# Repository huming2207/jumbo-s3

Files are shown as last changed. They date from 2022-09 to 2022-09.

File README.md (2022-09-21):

# jumbo-s3

PoC hardware design of ESP32-S3FN8 + 16MB (APS12808L-3OBM-BA) PSRAM

## Intro

As of September 2022, Espressif doesn't provide an official solution for ESP32-S3 that comes with more than 8MB PSRAM. However someone mentioned that the APS12808L works with ESP32-S3 but no open source design.

Therefore here comes my solution. It has been proven working fine. No modification needed for ESP-IDF. As long as the PSRAM support is enabled and set to octal mode, 80MHz, it should just works.

## Log

Here's a simple boot log that runs the APS12808L in octal SPI mode at 80MHz, and logs the free heap size.

```
ESP-ROM:esp32s3-20210327
Build:Mar 27 2021
rst:0x1 (POWERON),boot:0x8 (SPI_FAST_FLASH_BOOT)
SPIWP:0xee
mode:DIO, clock div:1
load:0x3fce3810,len:0x1808
load:0x403c9700,len:0xd6c
load:0x403cc700,len:0x2ed4
entry 0x403c992c
I (24) boot: ESP-IDF v5.1-dev-862-g09f7589ef2 2nd stage bootloader
I (25) boot: compile time Sep 20 2022 23:02:14
I (25) boot: chip revision: V001
I (29) boot_comm: chip revision: 1, min. bootloader chip revision: 0
I (36) qio_mode: Enabling default flash chip QIO
I (42) boot.esp32s3: Boot SPI Speed : 80MHz
I (46) boot.esp32s3: SPI Mode       : QIO
I (51) boot.esp32s3: SPI Flash Size : 4MB
I (56) boot: Enabling RNG early entropy source...
I (61) boot: Partition Table:
I (65) boot: ## Label            Usage          Type ST Offset   Length
I (72) boot:  0 nvs              WiFi data        01 02 00009000 00006000
I (79) boot:  1 phy_init         RF data          01 01 0000f000 00001000
I (87) boot:  2 factory          factory app      00 00 00010000 00100000
I (94) boot: End of partition table
I (99) boot_comm: chip revision: 1, min. application chip revision: 0
I (106) esp_image: segment 0: paddr=00010020 vaddr=3c020020 size=08a5ch ( 35420) map
I (120) esp_image: segment 1: paddr=00018a84 vaddr=3fc92700 size=03268h ( 12904) load
I (125) esp_image: segment 2: paddr=0001bcf4 vaddr=40374000 size=04324h ( 17188) load
I (135) esp_image: segment 3: paddr=00020020 vaddr=42000020 size=196fch (104188) map
I (155) esp_image: segment 4: paddr=00039724 vaddr=40378324 size=0a30ch ( 41740) load
I (164) esp_image: segment 5: paddr=00043a38 vaddr=50000000 size=00010h (    16) load
I (170) boot: Loaded app from partition at offset 0x10000
I (170) boot: Disabling RNG early entropy source...
I (184) octal_psram: vendor id    : 0x0d (AP)
I (184) octal_psram: dev id       : 0x02 (generation 3)
I (184) octal_psram: density      : 0x05 (128 Mbit)
I (189) octal_psram: good-die     : 0x01 (Pass)
I (195) octal_psram: Latency      : 0x01 (Fixed)
I (200) octal_psram: VCC          : 0x01 (3V)
I (205) octal_psram: SRF          : 0x01 (Fast Refresh)
I (211) octal_psram: BurstType    : 0x01 (Hybrid Wrap)
I (217) octal_psram: BurstLen     : 0x01 (32 Byte)
I (222) octal_psram: Readlatency  : 0x02 (10 cycles@Fixed)
I (228) octal_psram: DriveStrength: 0x00 (1/1)
W (233) PSRAM: DO NOT USE FOR MASS PRODUCTION! Timing parameters will be updated in future IDF version.
I (244) esp_psram: Found 16MB PSRAM device
I (248) esp_psram: Speed: 80MHz
I (252) cpu_start: Pro cpu up.
I (256) cpu_start: Starting app cpu, entry point is 0x40375378
I (0) cpu_start: App cpu up.
I (1167) esp_psram: SPI SRAM memory test OK
I (1176) cpu_start: Pro cpu start user code
I (1176) cpu_start: cpu freq: 160000000 Hz
I (1176) cpu_start: Application information:
I (1179) cpu_start: Project name:     main
I (1184) cpu_start: App version:      1
I (1188) cpu_start: Compile time:     Sep 20 2022 23:02:12
I (1195) cpu_start: ELF file SHA256:  1f3449a15147ac7a...
Warning: checksum mismatch between flashed and built applications. Checksum of built application is e6bd8ac9c4e022dd86afd168d00707482f76b53ee256de9e101a4846cd271af5
I (1201) cpu_start: ESP-IDF:          v5.1-dev-862-g09f7589ef2
I (1207) heap_init: Initializing. RAM available for dynamic allocation:
I (1215) heap_init: At 3FC963E8 len 00053328 (332 KiB): D/IRAM
I (1221) heap_init: At 3FCE9710 len 00005724 (21 KiB): STACK/DRAM
I (1228) heap_init: At 3FCF0000 len 00008000 (32 KiB): DRAM
I (1234) heap_init: At 600FE010 len 00001FF0 (7 KiB): RTCRAM
I (1241) esp_psram: Adding pool of 16384K of PSRAM memory to heap allocator
I (1249) spi_flash: detected chip: gd
I (1253) spi_flash: flash io: qio
W (1257) spi_flash: Detected size(8192k) larger than the size in the binary image header(4096k). Using the size in the binary image header.
I (1270) cpu_start: Starting scheduler on PRO CPU.
I (0) cpu_start: Starting scheduler on APP CPU.
I (1290) esp_psram: Reserving pool of 32K of internal memory for DMA/internal allocations
I (1290) test: Lay hou
I (1300) test: Max heap: 17117304

```

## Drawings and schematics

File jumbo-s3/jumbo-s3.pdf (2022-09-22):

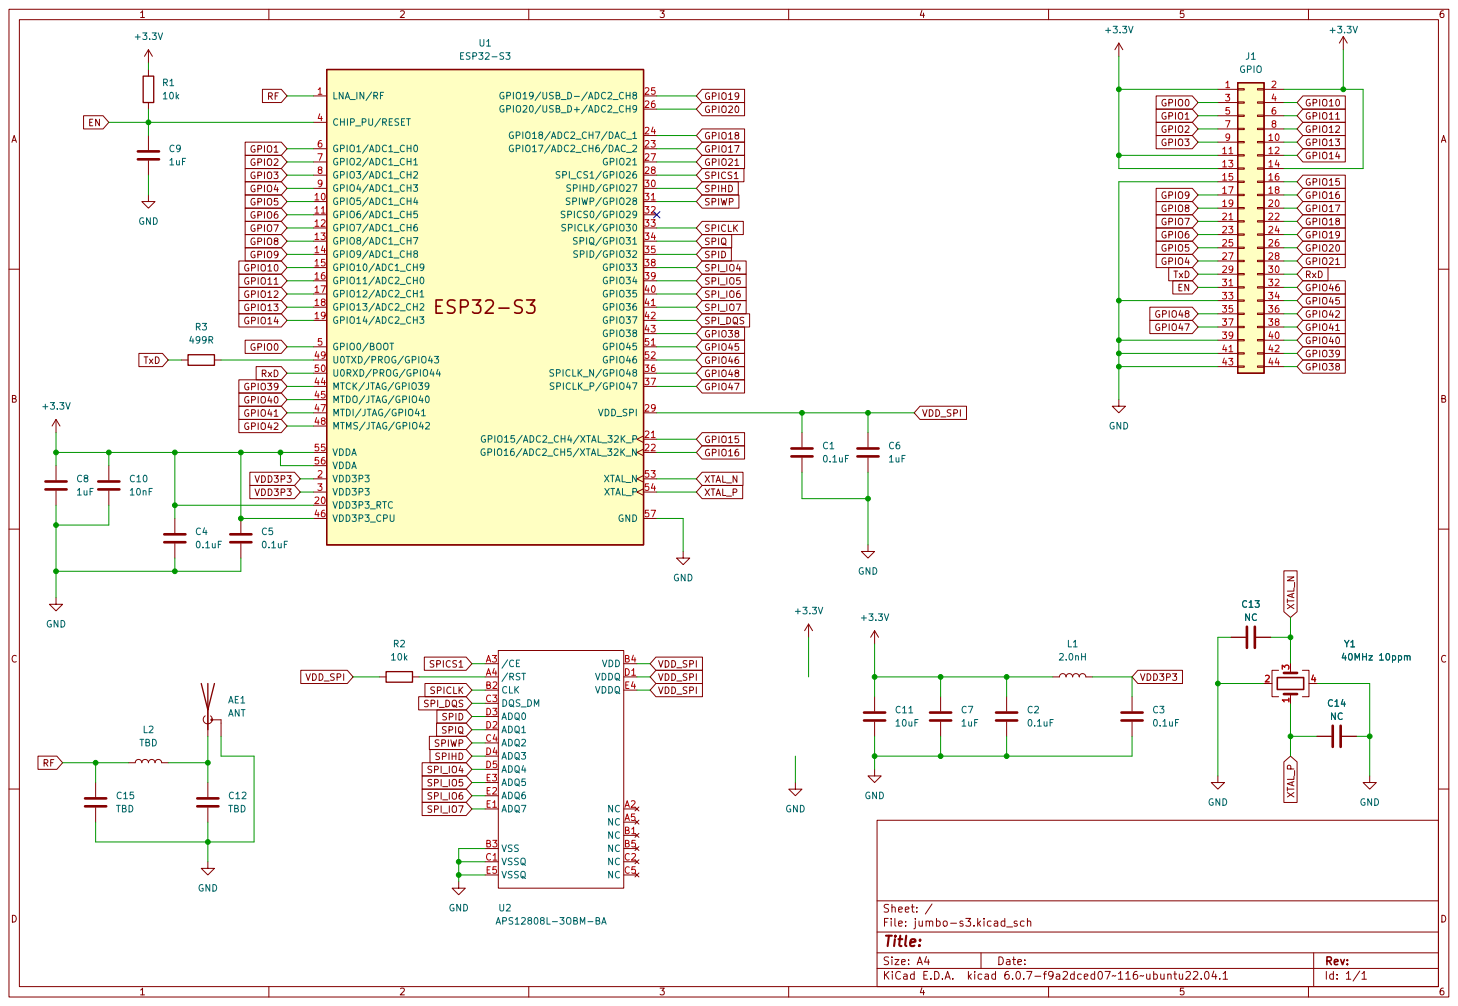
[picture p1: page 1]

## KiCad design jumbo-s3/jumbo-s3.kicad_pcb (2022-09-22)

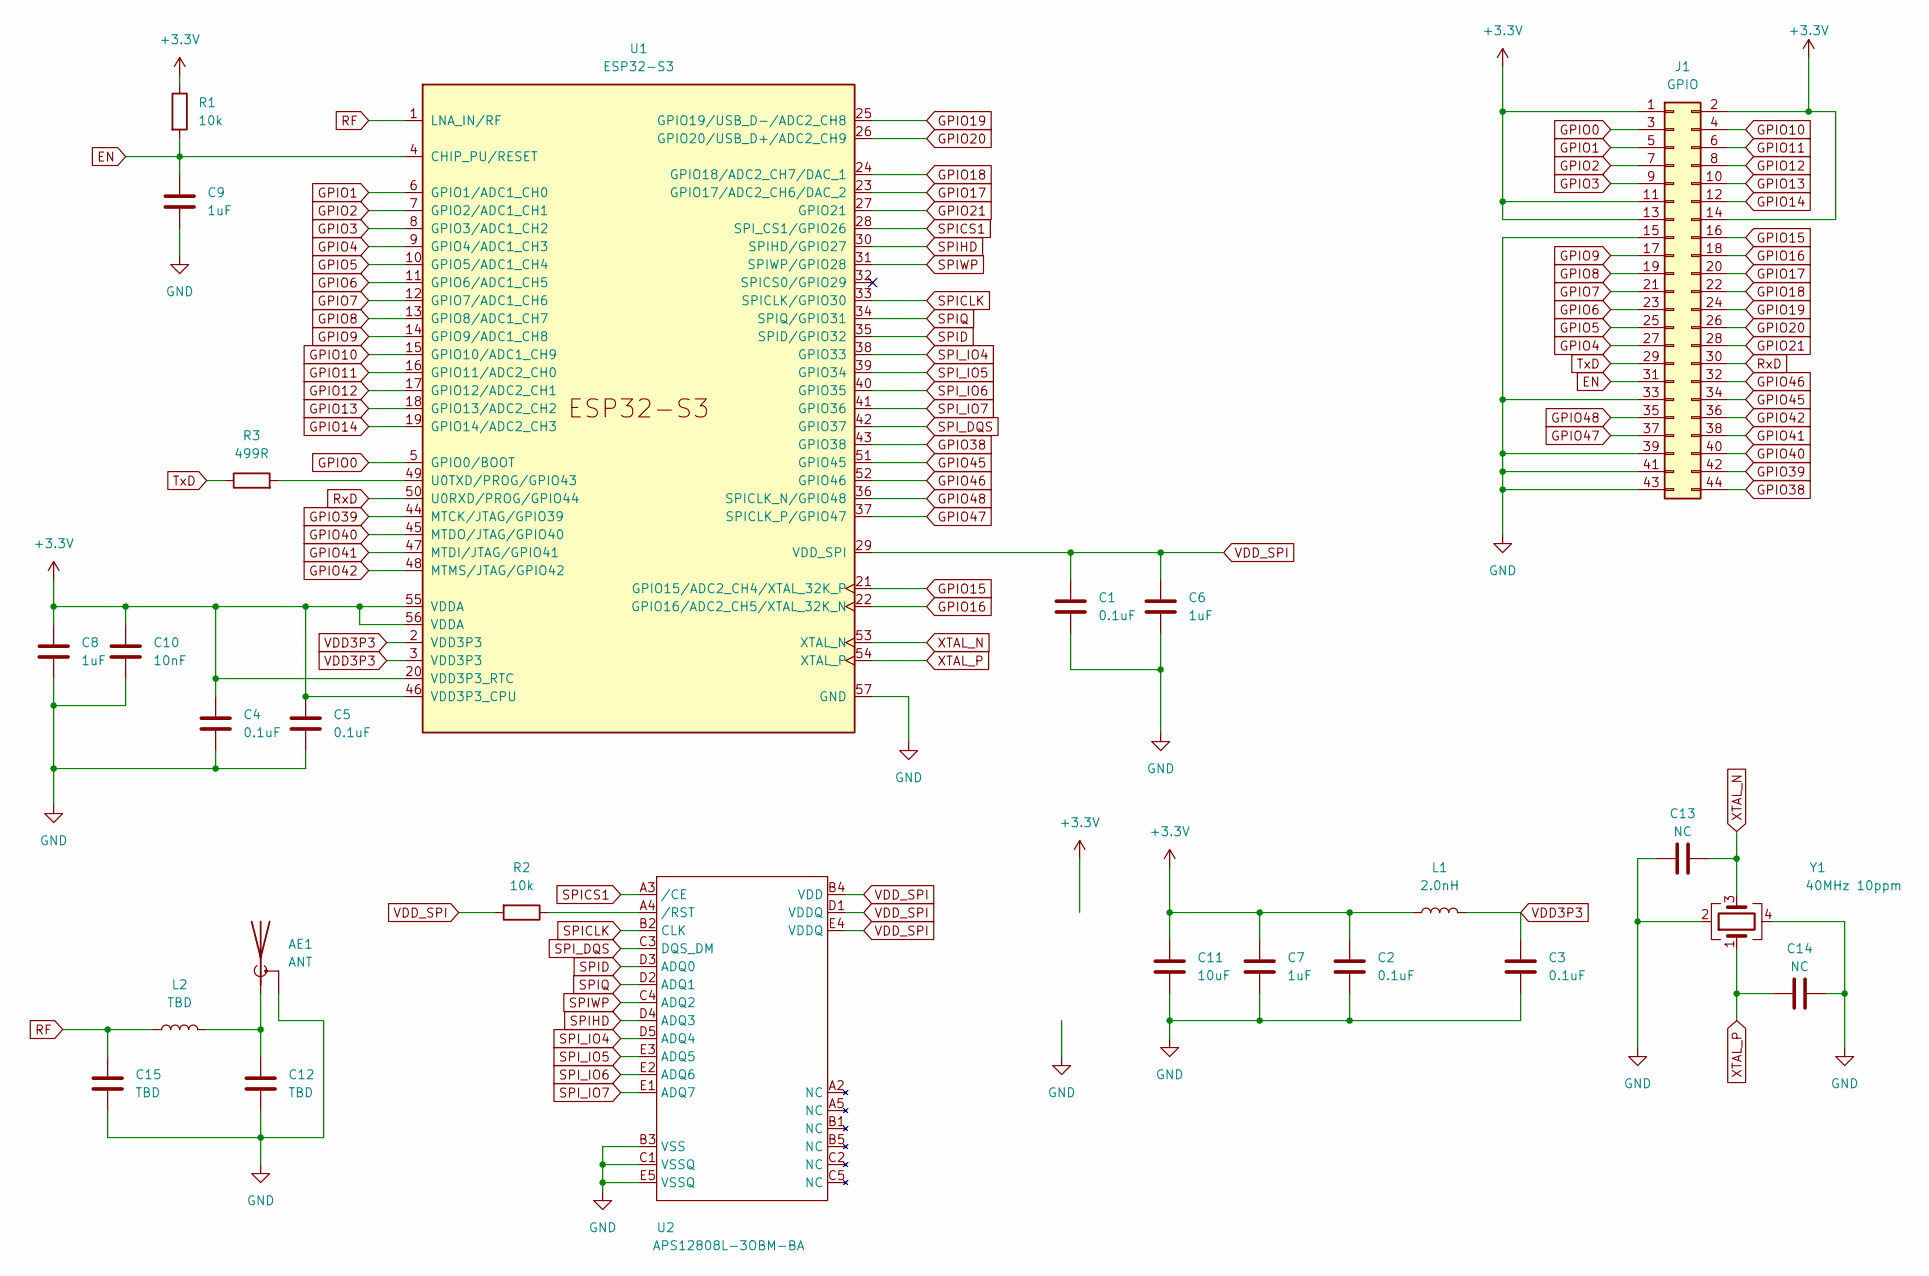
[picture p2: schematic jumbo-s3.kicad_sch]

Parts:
AE1: ANT; Texas_SWRA117D_2.4GHz_Left
C1, C2, C3, C4, C5: 0.1uF; C_0603_1608Metric_Pad1.08x0.95mm_HandSolder
C6, C7, C8, C9: 1uF; C_0603_1608Metric_Pad1.08x0.95mm_HandSolder
C10: 10nF; C_0603_1608Metric_Pad1.08x0.95mm_HandSolder
C11: 10uF; C_0603_1608Metric_Pad1.08x0.95mm_HandSolder
C12, C15: TBD; C_0603_1608Metric_Pad1.08x0.95mm_HandSolder
C13, C14: NC; C_0603_1608Metric_Pad1.08x0.95mm_HandSolder
J1: GPIO; PinHeader_2x22_P1.27mm_Vertical_SMD
L1: 2.0nH; L_0603_1608Metric_Pad1.05x0.95mm_HandSolder
L2: TBD; L_0603_1608Metric_Pad1.05x0.95mm_HandSolder
R1, R2: 10k; R_0603_1608Metric_Pad0.98x0.95mm_HandSolder
R3: 499R; R_0603_1608Metric_Pad0.98x0.95mm_HandSolder
U1: ESP32-S3; QFN-56-1EP_7x7mm_P0.4mm_EP5.6x5.6mm
U2: APS12808L-3OBM-BA; MINIBGA-24L
Y1: 40MHz 10ppm; Crystal_SMD_3225-4Pin_3.2x2.5mm_HandSoldering

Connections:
+3.3V: C2.1, C4.1, C5.1, C7.1, C8.2, C10.2, C11.1, J1.1, J1.2, J1.11, J1.13, J1.14, L1.1, R1.1, U1.20 (VDD3P3_RTC), U1.46 (VDD3P3_CPU), U1.55 (VDDA), U1.56 (VDDA)
EN: C9.1, J1.31, R1.2, U1.4 (CHIP_PU/RESET)
GND: AE1.2 (Shield), C1.2, C2.2, C3.2, C4.2, C5.2, C6.2, C7.2, C8.1, C9.2, C10.1, C11.2, C12.2, C13.1, C14.2, C15.1, J1.15, J1.33, J1.39, J1.41, J1.43, U1.57 (GND), U2.B3 (VSS), U2.C1 (VSSQ), U2.E5 (VSSQ), Y1.2, Y1.4
GPIO0: J1.3, U1.5 (GPIO0/BOOT)
GPIO1: J1.5, U1.6 (GPIO1/ADC1_CH0)
GPIO2: J1.7, U1.7 (GPIO2/ADC1_CH1)
GPIO3: J1.9, U1.8 (GPIO3/ADC1_CH2)
GPIO4: J1.27, U1.9 (GPIO4/ADC1_CH3)
GPIO5: J1.25, U1.10 (GPIO5/ADC1_CH4)
GPIO6: J1.23, U1.11 (GPIO6/ADC1_CH5)
GPIO7: J1.21, U1.12 (GPIO7/ADC1_CH6)
GPIO8: J1.19, U1.13 (GPIO8/ADC1_CH7)
GPIO9: J1.17, U1.14 (GPIO9/ADC1_CH8)
GPIO10: J1.4, U1.15 (GPIO10/ADC1_CH9)
GPIO11: J1.6, U1.16 (GPIO11/ADC2_CH0)
GPIO12: J1.8, U1.17 (GPIO12/ADC2_CH1)
GPIO13: J1.10, U1.18 (GPIO13/ADC2_CH2)
GPIO14: J1.12, U1.19 (GPIO14/ADC2_CH3)
GPIO15: J1.16, U1.21 (GPIO15/ADC2_CH4/XTAL_32K_P)
GPIO16: J1.18, U1.22 (GPIO16/ADC2_CH5/XTAL_32K_N)
GPIO17: J1.20, U1.23 (GPIO17/ADC2_CH6/DAC_2)
GPIO18: J1.22, U1.24 (GPIO18/ADC2_CH7/DAC_1)
GPIO19: J1.24, U1.25 (GPIO19/USB_D-/ADC2_CH8)
GPIO20: J1.26, U1.26 (GPIO20/USB_D+/ADC2_CH9)
GPIO21: J1.28, U1.27 (GPIO21)
GPIO38: J1.44, U1.43 (GPIO38)
GPIO39: J1.42, U1.44 (MTCK/JTAG/GPIO39)
GPIO40: J1.40, U1.45 (MTDO/JTAG/GPIO40)
GPIO41: J1.38, U1.47 (MTDI/JTAG/GPIO41)
GPIO42: J1.36, U1.48 (MTMS/JTAG/GPIO42)
GPIO45: J1.34, U1.51 (GPIO45)
GPIO46: J1.32, U1.52 (GPIO46)
GPIO47: J1.37, U1.37 (SPICLK_P/GPIO47)
GPIO48: J1.35, U1.36 (SPICLK_N/GPIO48)
unnamed: AE1.1 (A), C12.1, L2.2
unnamed: R2.1, U2.A4 (/RST)
unnamed: R3.2, U1.49 (U0TXD/PROG/GPIO43)
RF: C15.2, L2.1, U1.1 (LNA_IN/RF)
RxD: J1.30, U1.50 (U0RXD/PROG/GPIO44)
SPICLK: U1.33 (SPICLK/GPIO30), U2.B2 (CLK)
SPICS1: U1.28 (SPI_CS1/GPIO26), U2.A3 (/CE)
SPID: U1.35 (SPID/GPIO32), U2.D3 (ADQ0)
SPIHD: U1.30 (SPIHD/GPIO27), U2.D4 (ADQ3)
SPIQ: U1.34 (SPIQ/GPIO31), U2.D2 (ADQ1)
SPIWP: U1.31 (SPIWP/GPIO28), U2.C4 (ADQ2)
SPI_DQS: U1.42 (GPIO37), U2.C3 (DQS_DM)
SPI_IO4: U1.38 (GPIO33), U2.D5 (ADQ4)
SPI_IO5: U1.39 (GPIO34), U2.E3 (ADQ5)
SPI_IO6: U1.40 (GPIO35), U2.E2 (ADQ6)
SPI_IO7: U1.41 (GPIO36), U2.E1 (ADQ7)
TxD: J1.29, R3.1
VDD3P3: C3.1, L1.2, U1.2 (VDD3P3), U1.3 (VDD3P3)
VDD_SPI: C1.1, C6.1, R2.2, U1.29 (VDD_SPI), U2.B4 (VDD), U2.D1 (VDDQ), U2.E4 (VDDQ)
XTAL_N: C13.2, U1.53 (XTAL_N), Y1.3
XTAL_P: C14.1, U1.54 (XTAL_P), Y1.1

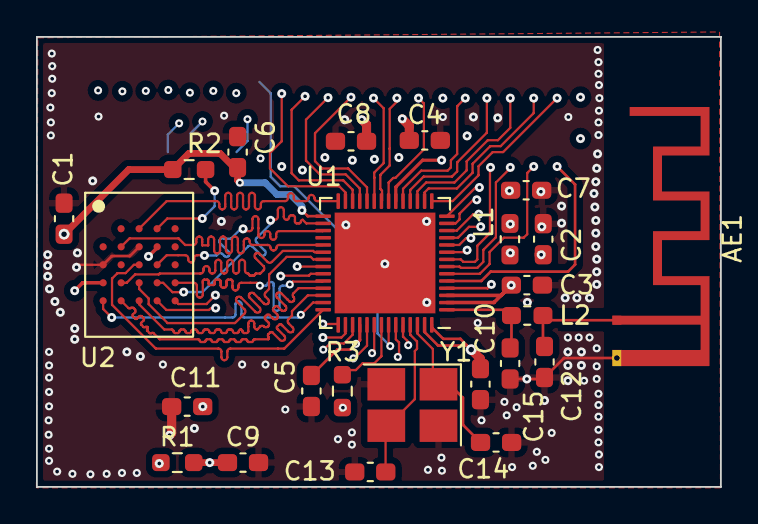
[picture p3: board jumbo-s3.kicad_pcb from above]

Board: 4 copper layers, 38.0 x 25.0 mm, 25 parts (1 on the bottom side), 55 nets.

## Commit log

2022-08-31 Add footprint & symbol ref
2022-09-01 schematic: add uC, flash and PSRAM
    [jumbo-s3.kicad_sch]
2022-09-02 Finish schematic
    [jumbo-s3.kicad_pcb, jumbo-s3.kicad_sch]
2022-09-03 pcb: rev. 1
    [jumbo-s3.kicad_pcb, jumbo-s3.kicad_sch]
2022-09-03 pcb: add rev 1 panel
    [panel.kicad_pcb]
2022-09-03 pcb: add rev 1 panel gerber
    [panel-B_Cu.gbl, panel-B_Mask.gbs, panel-B_Paste.gbp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]
2022-09-06 Update schematic PDF
2022-09-21 Rev 2: init
    [jumbo-s3.kicad_pcb, jumbo-s3.kicad_sch]
2022-09-21 rev2: pcb: connect everything up
    [jumbo-s3.kicad_pcb, jumbo-s3.kicad_sch]
2022-09-21 rev2: finalise PCB
    [jumbo-s3.kicad_pcb]
2022-09-21 rev2: pcb: final adjustments
    [jumbo-s3.kicad_pcb]
2022-09-21 rev2: generate panels
    [jumbo-s3.kicad_pcb]
2022-09-21 Rev 2.1: unify headers
    [jumbo-s3.kicad_pcb, jumbo-s3.kicad_sch]
2022-09-21 rev 2.1: fix warnings
    [jumbo-s3.kicad_pcb]
2022-09-22 Rev 2.1: final fixes
    [jumbo-s3.kicad_pcb]
2022-09-22 Rev 2.1: add panelised PCB/gerber
    [panel-B_Cu.gbl, panel-B_Mask.gbs, panel-B_Paste.gbp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]
